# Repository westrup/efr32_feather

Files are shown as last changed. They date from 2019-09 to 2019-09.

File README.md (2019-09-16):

EFR32 Feather Board
===================

This is an Adafruit Feather compatible PCB with a Silicon Labs EFR32 MCU.
This MCU supports 2.4GHz radio such as BLE, Zigbee, Thread

Hardware components:
* MCU: EFR32 with 1024kB FLASH, 256kB RAM [EFR32MG12P332F1024GM48](https://www.silabs.com/products/wireless/mesh-networking/efr32mg-mighty-gecko-zigbee-thread-soc/device.efr32mg12p332f1024gm48)
* Alternative MCU: EFR32 with 512kB FLASH, 64kB RAM [EFR32BG13P532F512GM48](https://www.silabs.com/products/wireless/bluetooth/blue-gecko-bluetooth-low-energy-socs/device.efr32bg13p532f512gm48)
* USB Serial interface: [CP2102N](https://www.silabs.com/products/interface/usb-bridges/usbxpress-usb-bridges/device.cp2102n-qfn24)
* 3.3V LDO: [AP2112K](https://www.diodes.com/products/power-management/low-dropout-regulators/part/AP2112)
* Charging: [MCP73832](https://www.microchip.com/wwwproducts/en/MCP73832)

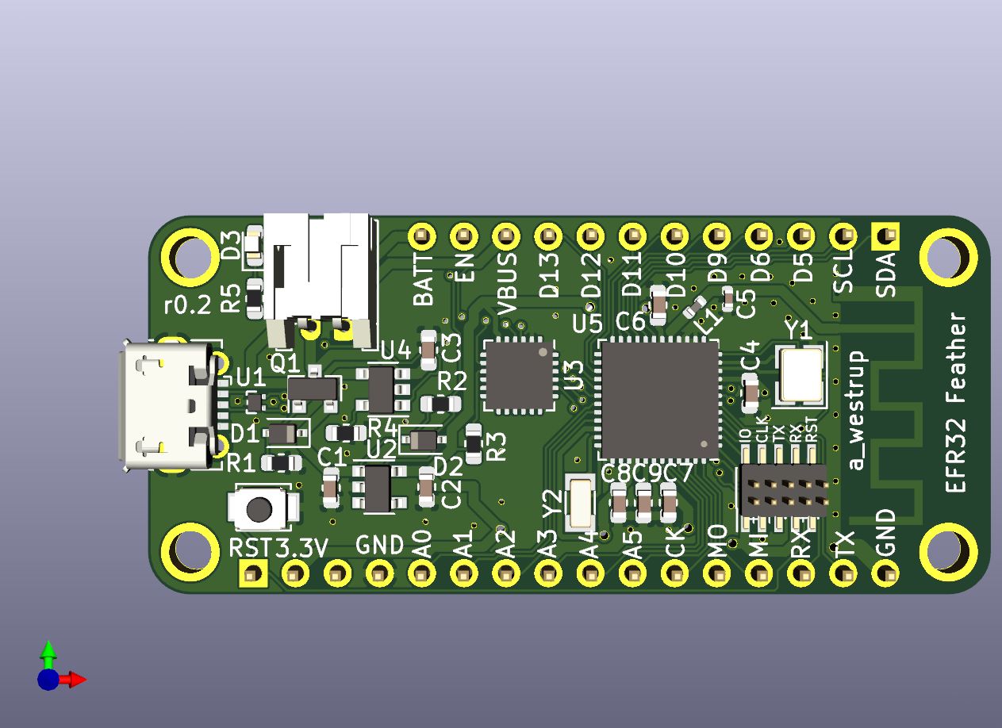
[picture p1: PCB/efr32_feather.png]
EFR32 Feather


Firmware example:
* Using [Zephyr](https://www.zephyrproject.org/)
* Board definition in FW/boards/arm/efr32\_feather

Build instruction:

    mkdir FW/build
    cd FW/build
    source ZEPHYR-DIR/zephyr-env.sh
    cmake -Gninja ..
    ninja flash

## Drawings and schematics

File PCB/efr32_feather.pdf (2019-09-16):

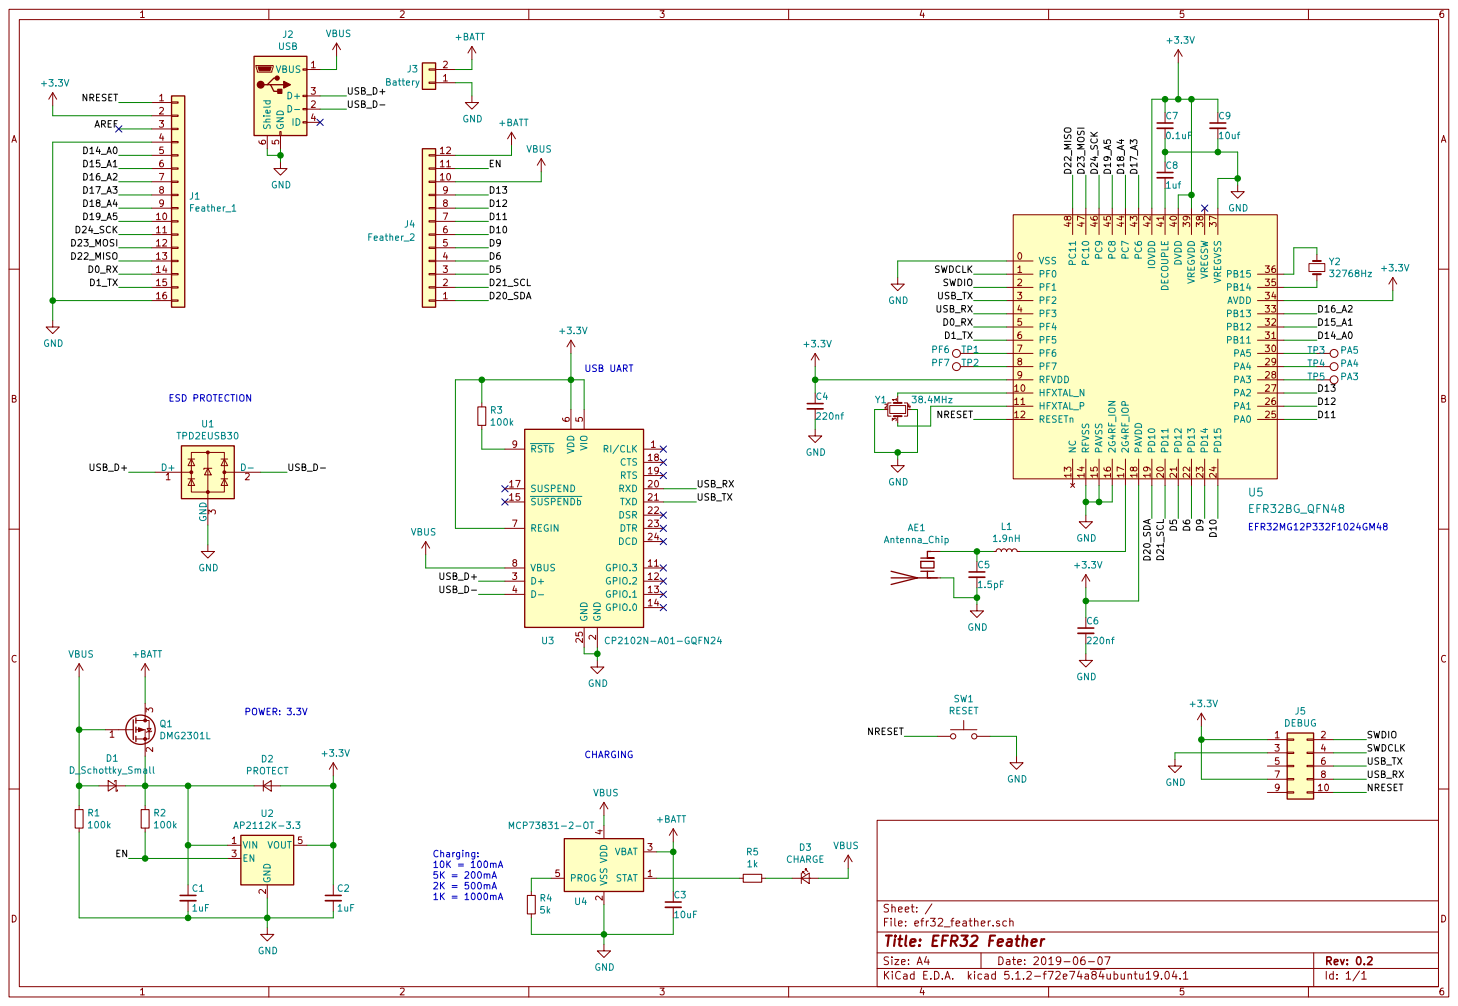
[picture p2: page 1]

2 RXD 20 TXD 21 DSR 22 DTR 23 DCD 24 GND 25 D+ 3 D- 4 VIO

4 PROG 5 U4 MCP73831-2-OT +BATT GND

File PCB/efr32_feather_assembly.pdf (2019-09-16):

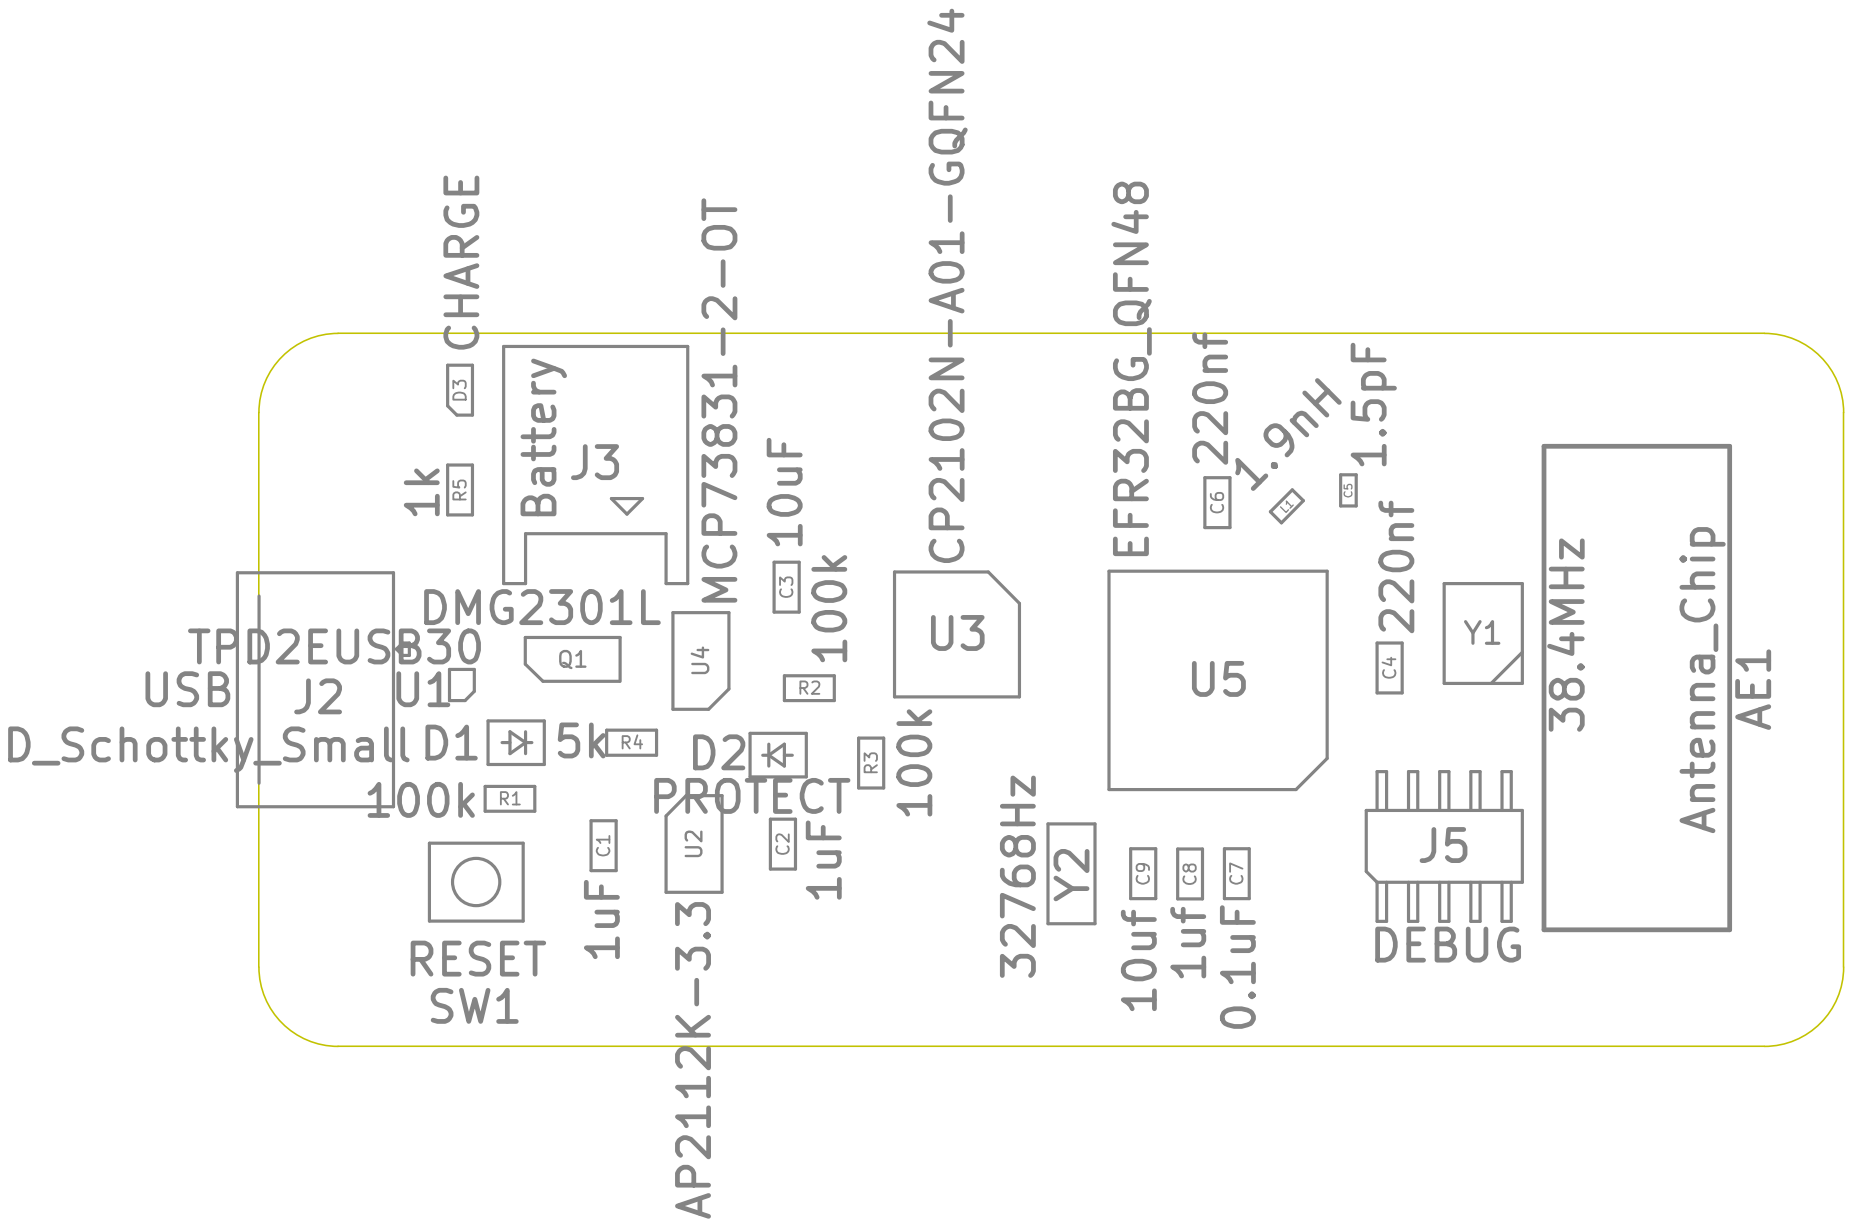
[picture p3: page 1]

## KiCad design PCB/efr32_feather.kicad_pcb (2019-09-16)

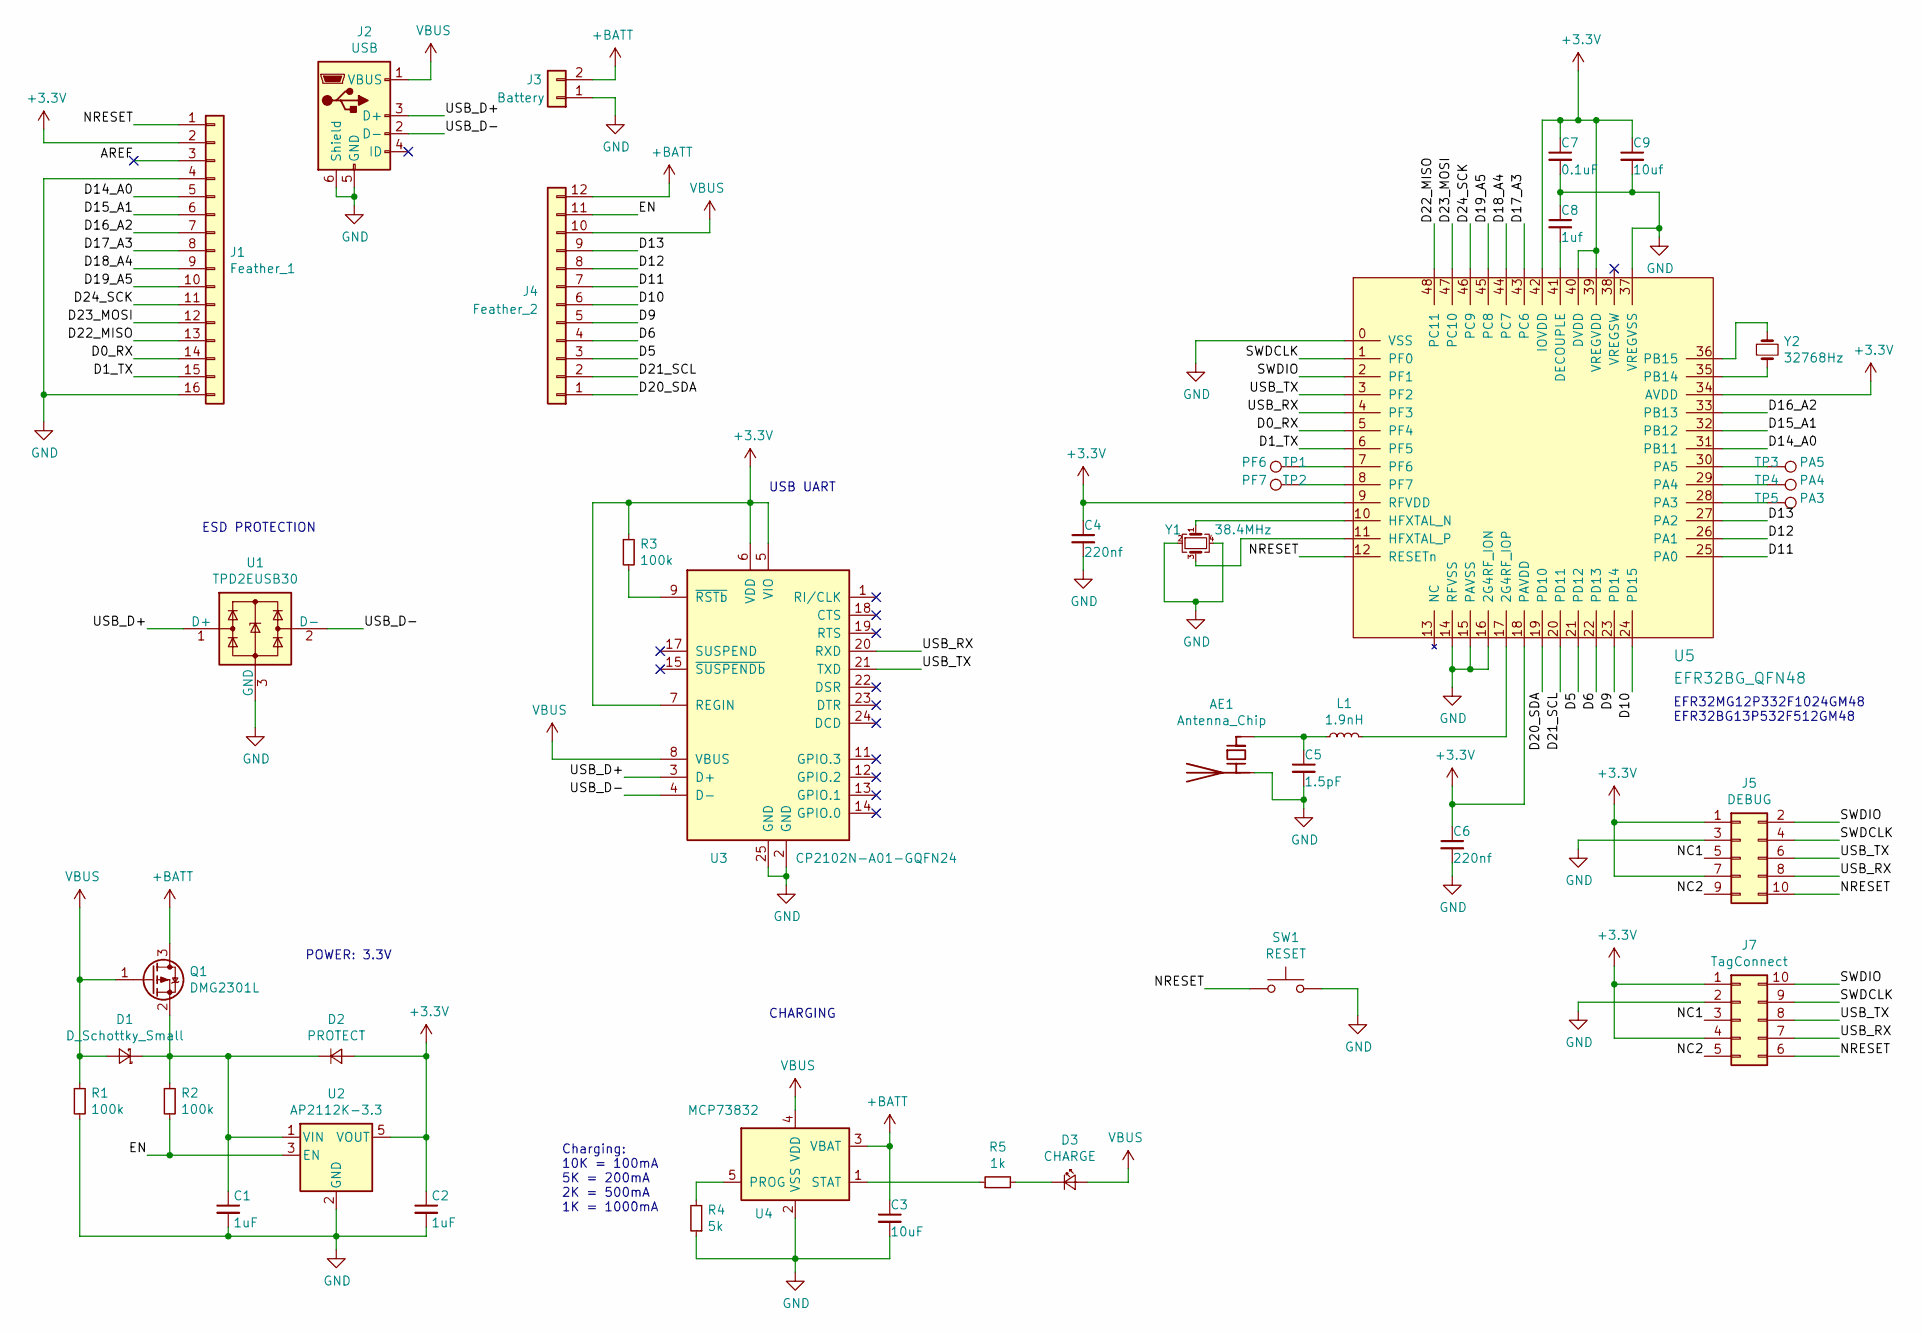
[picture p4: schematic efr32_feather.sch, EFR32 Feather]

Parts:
AE1: Antenna_Chip; Texas_SWRA117D_2.4GHz_Right
C1, C2: 1uF; C_0603_1608Metric
C3: 10uF; C_0603_1608Metric
C4, C6: 220nf; C_0603_1608Metric
C5: 1.5pF; C_0402_1005Metric
C7: 0.1uF; C_0603_1608Metric
C8: 1uf; C_0603_1608Metric
C9: 10uf; C_0603_1608Metric
D1: D_Schottky_Small; D_SOD-323
D2: PROTECT; D_SOD-323
D3: CHARGE; LED_0603_1608Metric
J1: Feather_1; PinHeader_1x16_P2.54mm_Vertical
J2: USB; USB_Micro-B_Molex-105017-0001
J3: Battery; JST_PH_S2B-PH-K_1x02_P2.00mm_Horizontal
J4: Feather_2; PinHeader_1x12_P2.54mm_Vertical
J5: DEBUG; PinHeader_2x05_P1.27mm_Vertical_SMD
J7: TagConnect; Tag-Connect_TC2050-IDC-NL_2x05_P1.27mm_Vertical
L1: 1.9nH; L_0402_1005Metric
Q1: DMG2301L; SOT-23
R1, R2, R3: 100k; R_0603_1608Metric
R4: 5k; R_0603_1608Metric
R5: 1k; R_0603_1608Metric
SW1: RESET; SW_SPST_B3U-1000P
TP1: PF6; TestPoint_Pad_D1.0mm
TP2: PF7; TestPoint_Pad_D1.0mm
TP3: PA5; TestPoint_Pad_D1.0mm
TP4: PA4; TestPoint_Pad_D1.0mm
TP5: PA3; TestPoint_Pad_D1.0mm
U1: TPD2EUSB30; Texas_DRT-3
U2: AP2112K-3.3; SOT-23-5
U3: CP2102N-A01-GQFN24; QFN-24-1EP_4x4mm_P0.5mm_EP2.6x2.6mm
U4: MCP73832; SOT-23-5
U5: EFR32BG_QFN48; QFN-48-1_PIN0_EP_7x7mm_P0.5mm_EP5.3x5.3mm
Y1: 38.4MHz; Crystal_SMD_3225-4Pin_3.2x2.5mm
Y2: 32768Hz; Crystal_SMD_3215-2Pin_3.2x1.5mm

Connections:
+3V3: C2.1, C4.1, C6.1, C7.1, C9.1, D2.2 (A), J1.2, J5.1, J5.7, J7.1, J7.4, R3.1, U2.5 (VOUT), U3.5 (VIO), U3.6 (VDD), U3.7 (REGIN), U5.9 (RFVDD), U5.18 (PAVDD), U5.34 (AVDD), U5.39 (VREGVDD), U5.40 (DVDD), U5.42 (IOVDD)
+BATT: C3.1, J3.2, J4.12, Q1.3 (D), U4.3 (VBAT)
/AREF: J1.3
/D0_RX: J1.14, U5.5 (PF4)
/D1_TX: J1.15, U5.6 (PF5)
/D5: J4.3, U5.21 (PD12)
/D6: J4.4, U5.22 (PD13)
/D9: J4.5, U5.23 (PD14)
/D10: J4.6, U5.24 (PD15)
/D11: J4.7, U5.25 (PA0)
/D12: J4.8, U5.26 (PA1)
/D13: J4.9, U5.27 (PA2)
/D14_A0: J1.5, U5.31 (PB11)
/D15_A1: J1.6, U5.32 (PB12)
/D16_A2: J1.7, U5.33 (PB13)
/D17_A3: J1.8, U5.43 (PC6)
/D18_A4: J1.9, U5.44 (PC7)
/D19_A5: J1.10, U5.45 (PC8)
/D20_SDA: J4.1, U5.19 (PD10)
/D21_SCL: J4.2, U5.20 (PD11)
/D22_MISO: J1.13, U5.48 (PC11)
/D23_MOSI: J1.12, U5.47 (PC10)
/D24_SCK: J1.11, U5.46 (PC9)
/EN: J4.11, R2.2, U2.3 (EN)
/NC1: J5.5, J7.3
/NC2: J5.9, J7.5
/NRESET: J1.1, J5.10, J7.6, SW1.1, U5.12 (RESETn)
/SWDCLK: J5.4, J7.9, U5.1 (PF0)
/SWDIO: J5.2, J7.10, U5.2 (PF1)
/USB_D+: J2.3 (D+), U1.1 (D+), U3.3 (D+)
/USB_D-: J2.2 (D-), U1.2 (D-), U3.4 (D-)
/USB_RX: J5.8, J7.7, U3.20 (RXD), U5.4 (PF3)
/USB_TX: J5.6, J7.8, U3.21 (TXD), U5.3 (PF2)
GND: AE1.2 (PCB_Trace), C1.2, C2.2, C3.2, C4.2, C5.2, C6.2, C7.2, C8.1, C9.2, J1.4, J1.16, J2.5 (GND), J2.6 (Shield), J3.1, J5.3, J7.2, R1.2, R4.1, SW1.2, U1.3 (GND), U2.2 (GND), U3.2 (GND), U3.25 (GND), U4.2 (VSS), U5.0 (VSS), U5.14 (RFVSS), U5.15 (PAVSS), U5.16 (2G4RF_ION), U5.37 (VREGVSS), Y1.2, Y1.4
unnamed: AE1.1 (FEED), C5.1, L1.1
unnamed: C1.1, D1.1 (K), D2.1 (K), Q1.2 (S), R2.1, U2.1 (VIN)
unnamed: C8.2, U5.41 (DECOUPLE)
unnamed: D3.1 (K), R5.2
unnamed: L1.2, U5.17 (2G4RF_IOP)
unnamed: R3.2, U3.9 (~RSTb)
unnamed: R4.2, U4.5 (PROG)
unnamed: R5.1, U4.1 (STAT)
unnamed: TP1.1, U5.7 (PF6)
unnamed: TP2.1, U5.8 (PF7)
unnamed: TP3.1, U5.30 (PA5)
unnamed: TP4.1, U5.29 (PA4)
unnamed: TP5.1, U5.28 (PA3)
unnamed: U5.10 (HFXTAL_N), Y1.1
unnamed: U5.11 (HFXTAL_P), Y1.3
unnamed: U5.35 (PB14), Y2.2
unnamed: U5.36 (PB15), Y2.1
VBUS: D1.2 (A), D3.2 (A), J2.1 (VBUS), J4.10, Q1.1 (G), R1.1, U3.8 (VBUS), U4.4 (VDD)

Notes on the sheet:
Charging: 10K = 100mA 5K = 200mA 2K = 500mA 1K = 1000mA
CHARGING
POWER: 3.3V
USB UART
ESD PROTECTION
EFR32MG12P332F1024GM48 EFR32BG13P532F512GM48

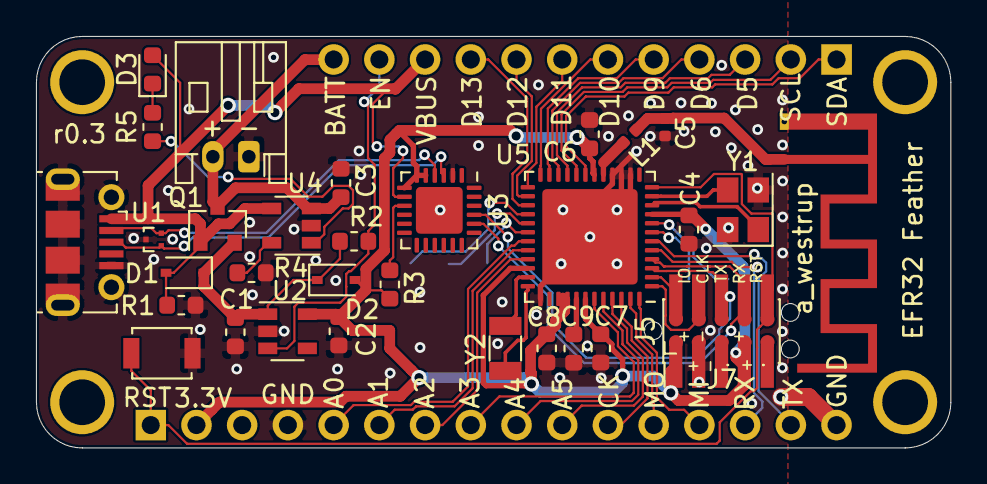
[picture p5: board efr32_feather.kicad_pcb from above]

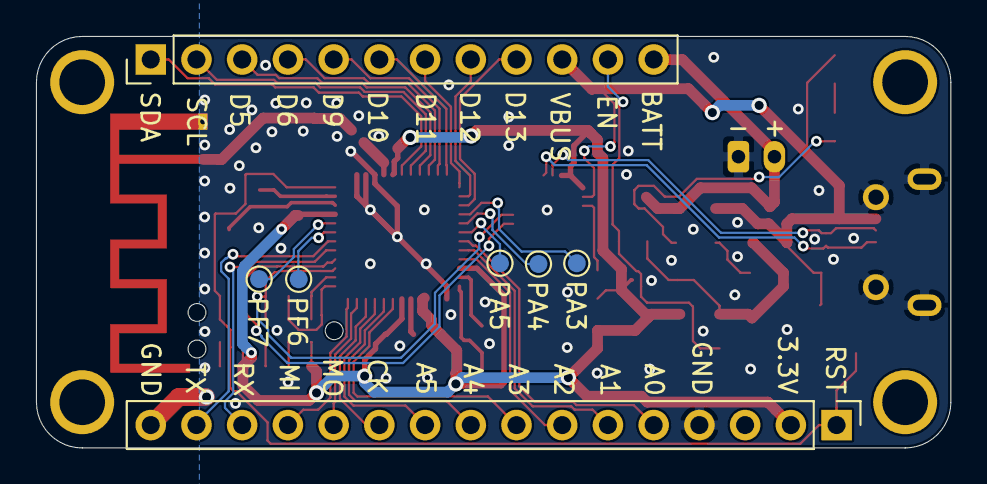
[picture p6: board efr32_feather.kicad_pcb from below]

Board: 2 copper layers, 50.8 x 22.9 mm, 40 parts (7 on the bottom side), 51 nets.

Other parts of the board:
PCB**: VAL**; PCB_FeatherWing

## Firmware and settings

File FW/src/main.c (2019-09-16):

#include <zephyr.h>
#include <misc/printk.h>
#include <device.h>
#include <gpio.h>

void main(void)
{
	printk("Hello World! %s\n", CONFIG_BOARD);
	int cnt = 0;
	struct device *gpio_dev = device_get_binding(LED0_GPIO_CONTROLLER);
	/* Set LED pin as output */
	gpio_pin_configure(gpio_dev, LED0_GPIO_PIN, GPIO_DIR_OUT | GPIO_PUD_PULL_UP);

	struct device *gpio1_dev = device_get_binding(LED1_GPIO_CONTROLLER);
	/* Set LED pin as output */
	gpio_pin_configure(gpio1_dev, LED1_GPIO_PIN, GPIO_DIR_OUT);

	while (1) {
		/* Set pin to HIGH/LOW every 1 second */
		gpio_pin_write(gpio_dev, LED0_GPIO_PIN, cnt % 2);
		gpio_pin_write(gpio1_dev, LED1_GPIO_PIN, cnt % 2);
		cnt++;
		k_sleep(1000);
	}

}

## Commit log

2019-09-16 EFR32 Feather
    [efr32_feather-B_Cu.gbr, efr32_feather-B_Mask.gbr, efr32_feather-B_Paste.gbr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]
2019-09-16 PIN names on silk screen
    [efr32_feather-B_Cu.gbr, efr32_feather-B_Mask.gbr, efr32_feather-B_Paste.gbr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]
2019-09-16 Reversed pin header, better antenna traces, reset button
    [efr32_feather-B_Cu.gbr, efr32_feather-B_Mask.gbr, efr32_feather-B_Paste.gbr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]
2019-09-16 r0.2: moved antenna matching components, more silk screen
    [efr32_feather-B_Cu.gbr, efr32_feather-B_Mask.gbr, efr32_feather-B_Paste.gbr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]
2019-09-16 Add ESD protection for USB
    [efr32_feather-B_Cu.gbr, efr32_feather-B_Mask.gbr, efr32_feather-B_Paste.gbr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]
2019-09-16 Move HW files to PCB/ and add README file
    [efr32_feather-B_Cu.gbr, efr32_feather-B_Mask.gbr, efr32_feather-B_Paste.gbr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]
2019-09-16 Change debug connector
    [efr32_feather.kicad_pcb, efr32_feather.sch]
